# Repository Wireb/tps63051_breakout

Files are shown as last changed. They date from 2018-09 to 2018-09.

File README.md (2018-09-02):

# TPS63051 breakout
This design is a simple breakout card for the TPS63051 buck boost 2.5V to 5.5V Vin to 3.3V @ 0.5A Vout regulator. 
Main reason was to run the reg though it's paces and see how bad the package was to hand place and solder. (not too bad better than solder lug packages) 
So far no issues found tested at 2.5V to 5.5V in and no load, 220mA and 440mA Vout (all stable at 3.3Vout) 
License is MIT so do what you want with it just don't litigate me. 

## KiCad
This is a KiCad 5.0 project. 

## documentation
This is a XLS/PDF dump of the spreadsheet documentation I was using during development. 

## OSHpark PCBs
PCB design can be found here:
https://www.oshpark.com/shared_projects/cPTJPkIs

Copyright (c) 2018 Peter Shabino

Permission is hereby granted, free of charge, to any person obtaining a copy of this hardware, software, and associated documentation files 
(the "Product"), to deal in the Product without restriction, including without limitation the rights to use, copy, modify, merge, publish, 
distribute, sublicense, and/or sell copies of the Product, and to permit persons to whom the Product is furnished to do so, subject to the 
following conditions:

The above copyright notice and this permission notice shall be included in all copies or substantial portions of the Product.

THE PRODUCT IS PROVIDED "AS IS", WITHOUT WARRANTY OF ANY KIND, EXPRESS OR IMPLIED, INCLUDING BUT NOT LIMITED TO THE WARRANTIES OF 
MERCHANTABILITY, FITNESS FOR A PARTICULAR PURPOSE AND NONINFRINGEMENT. IN NO EVENT SHALL THE AUTHORS OR COPYRIGHT HOLDERS BE LIABLE 
FOR ANY CLAIM, DAMAGES OR OTHER LIABILITY, WHETHER IN AN ACTION OF CONTRACT, TORT OR OTHERWISE, ARISING FROM, OUT OF OR IN CONNECTION 
WITH THE PRODUCT OR THE USE OR OTHER DEALINGS IN THE PRODUCT.

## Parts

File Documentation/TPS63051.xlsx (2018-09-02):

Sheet: BOM
 |  |  |  |  | 3 | $10.35
Q | part number | footprint | ref_des | cost | extended | ext cost | link
2 | 0 | digikey-footprints:0603 | R2 R3 | $0.10 | 6 | $0.60 | https://www.digikey.com/product-detail/en/panasonic-electronic-components/ERJ-3GEY0R00V/P0.0GCT-ND/134711
1 | 1.5uH | PJS_smt_parts:SMT_passive_1008 | L1 | $0.42 | 3 | $1.26 | https://www.digikey.com/products/en?keywords=490-10574-1-ND
1 | 100k | digikey-footprints:0603 | R1 | $0.10 | 3 | $0.30 | https://www.digikey.com/product-detail/en/bourns-inc/CR0603-FX-1003HLF/CR0603-FX-1003HLFCT-ND/4247695
3 | 10uF | digikey-footprints:0603 | C1 C3 C4 | $0.22 | 9 | $1.98 | https://www.digikey.com/product-detail/en/taiyo-yuden/LMK107BBJ106MALT/587-3258-1-ND/3662218
1 | 1M | digikey-footprints:0603 | R4 | $0.10 | 3 | $0.30 | https://www.digikey.com/product-detail/en/yageo/RC0603FR-071ML/311-1.00MHRCT-ND/729791
1 | 1nF | digikey-footprints:0603 | C2 | $0.10 | 3 | $0.30 | https://www.digikey.com/product-detail/en/kemet/C0603C102J5RACTU/399-1083-1-ND/411358
0 | EN | Pin_Headers:Pin_Header_Straight_1x02_Pitch2.54mm | J2 |  | 0 | $0.00
0 | Metroid | PJS-icons:metroid | icon1 |  | 0 | $0.00
0 | Pgood | Pin_Headers:Pin_Header_Straight_1x02_Pitch2.54mm | J4 |  | 0 | $0.00
1 | TPS63051 | PJS_smt_parts:TI_VQFN_12 | U1 | $1.87 | 3 | $5.61 | https://www.digikey.com/product-detail/en/texas-instruments/TPS63051RMWR/296-42650-1-ND/5455915
0 | Vin | Degson:DG301-5.002P-12 | J1 |  | 0 | $0.00
0 | Vout | Degson:DG301-5.002P-12 | J3 |  | 0 | $0.00

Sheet: Calcs
 | Vin | Vout
Boost duty cycle | 2.5 | 3.3 | 0.2424242424
 | Iout | n (eff)
input current boost | 0.5 | 0.9 | 0.7333333333
 | f (MHz) | L (uH) | n (eff) | Iout |  | fudge factor
Boost Ipeak | 2.5 | 1.5 | 0.9 | 0.5 | 0.8141414141 | 0.2 | 0.976969697
 | Vin | vout
Buck duty cycle | 5.5 | 3.3 | 0.6
 | Iout | n (eff)
input current buck | 0.5 | 0.9 | 0.3333333333

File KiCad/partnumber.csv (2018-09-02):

Q | part number | footprint | ref_des
2 | 0 | digikey-footprints:0603 | R2 R3
1 | 1.5uH | PJS_smt_parts:SMT_passive_1008 | L1
1 | 100k | digikey-footprints:0603 | R1
3 | 10uF | digikey-footprints:0603 | C1 C3 C4
1 | 1M | digikey-footprints:0603 | R4
1 | 1nF | digikey-footprints:0603 | C2
1 | EN | Pin_Headers:Pin_Header_Straight_1x02_Pitch2.54mm | J2
1 | Metroid | PJS-icons:metroid | icon1
1 | Pgood | Pin_Headers:Pin_Header_Straight_1x02_Pitch2.54mm | J4
1 | TPS63051 | PJS_smt_parts:TI_VQFN_12 | U1
1 | Vin | Degson:DG301-5.002P-12 | J1
1 | Vout | Degson:DG301-5.002P-12 | J3

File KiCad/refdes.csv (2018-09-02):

ref_des | part number | footprint
C1 | 10uF | digikey-footprints:0603
C2 | 1nF | digikey-footprints:0603
C3 | 10uF | digikey-footprints:0603
C4 | 10uF | digikey-footprints:0603
J1 | Vin | Degson:DG301-5.002P-12
J2 | EN | Pin_Headers:Pin_Header_Straight_1x02_Pitch2.54mm
J3 | Vout | Degson:DG301-5.002P-12
J4 | Pgood | Pin_Headers:Pin_Header_Straight_1x02_Pitch2.54mm
L1 | 1.5uH | PJS_smt_parts:SMT_passive_1008
R1 | 100k | digikey-footprints:0603
R2 | 0 | digikey-footprints:0603
R3 | 0 | digikey-footprints:0603
R4 | 1M | digikey-footprints:0603
U1 | TPS63051 | PJS_smt_parts:TI_VQFN_12
icon1 | Metroid | PJS-icons:metroid

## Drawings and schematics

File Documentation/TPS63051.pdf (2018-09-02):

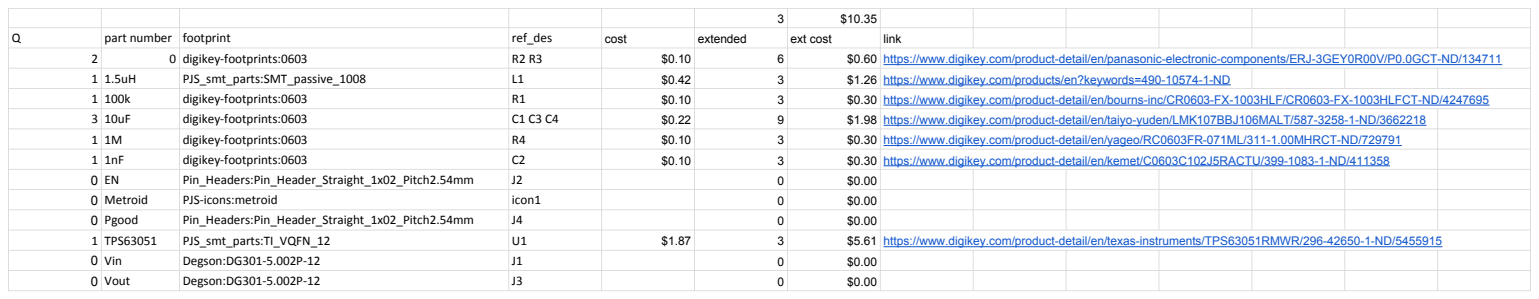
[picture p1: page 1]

Vin | Vout
Boost duty cycle | 2.5 | 3.3 | 0.2424242424

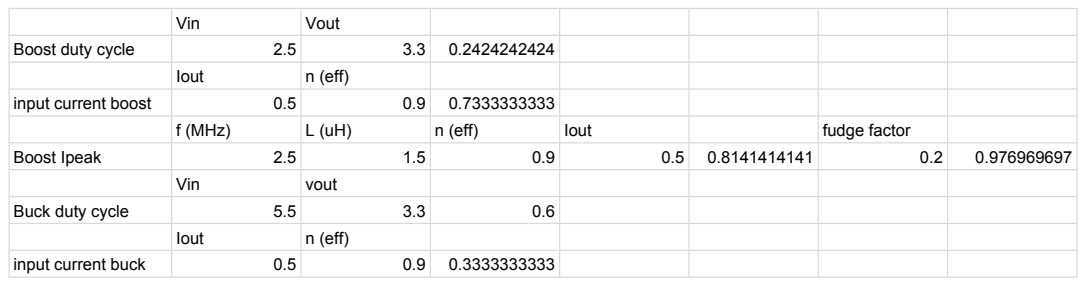
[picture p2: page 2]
Iout; n (eff); input current boost; f (MHz); fudge factor; Boost Ipeak; Vin; vout; Buck duty cycle; input current buck

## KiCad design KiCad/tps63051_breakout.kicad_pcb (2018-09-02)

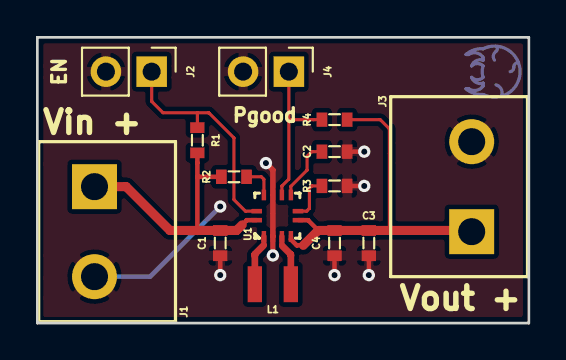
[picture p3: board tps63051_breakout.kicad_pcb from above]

Board: 2 copper layers, 27.3 x 15.9 mm, 15 parts (1 on the bottom side), 10 nets.

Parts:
C1, C3, C4: 10uF; 0603
C2: 1nF; 0603
J1: Vin; DG301-5.002P-12
J2: EN; Pin_Header_Straight_1x02_Pitch2.54mm
J3: Vout; DG301-5.002P-12
J4: Pgood; Pin_Header_Straight_1x02_Pitch2.54mm
L1: 1.5uH; SMT_passive_1008
R1: 100k; 0603
R2, R3: 0; 0603
R4: 1M; 0603
U1: TPS63051; TI_VQFN_12
icon1: Metroid; metroid

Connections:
GND: C1.2, C2.2, C3.2, C4.2, J1.2, J2.2, J3.2, J4.2, R3.2, U1.2, U1.9
unnamed: C1.1, J1.1, R1.1, R2.2, U1.12
unnamed: C2.1, U1.7
unnamed: C3.1, C4.1, J3.1, R4.1, U1.4, U1.5
unnamed: J2.1, R1.2, U1.11
unnamed: J4.1, R4.2, U1.8
unnamed: L1.1, U1.3
unnamed: L1.2, U1.1
unnamed: R2.1, U1.10
unnamed: R3.1, U1.6

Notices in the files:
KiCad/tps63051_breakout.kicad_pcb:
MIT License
